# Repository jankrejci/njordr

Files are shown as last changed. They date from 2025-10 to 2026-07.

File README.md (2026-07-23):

# vetroplach

An ultrasonic anemometer: KiCad PCB designs and ESP32-S3 firmware.

## Layout

- `firmware/vetroplach/` — ESP32-S3 firmware (Rust, esp-hal + Embassy)
- `pcb/vetroplach-board/` — main controller board
- `pcb/sensor-board/` — environmental sensor board
- `pcb/components/` — shared KiCad symbol and footprint library
- `nix/` — flake modules: toolchain, checks, dev shells
- `docs/` — design notes and simulations

## Prerequisites

Everything builds through [Nix](https://nixos.org/download/) flakes; no
manual rustup, espup, or KiCad setup is needed. Flashing uses
`probe-rs`; complete the
[probe setup](https://probe.rs/docs/getting-started/probe-setup/#linux-udev-rules),
especially the udev rules on Linux.

## Firmware

Enter the dev shell (pins the Xtensa toolchain, probe-rs, espflash) and
build from the crate directory:

```bash
nix develop
cd firmware/vetroplach
cargo build --release
```

Build and flash:

```bash
cargo run --release
```

Or run an example:

```bash
cargo run --release --example sonic-dual
```

## PCB

DRC/ERC gates and fabrication outputs run through the flake:

```bash
nix develop .#pcb    # KiCad + kibot shell
nix run .#kibot -- -c jlcpcb.kibot.yaml \
  -b pcb/vetroplach-board/vetroplach-board.kicad_pcb \
  -e pcb/vetroplach-board/vetroplach-board.kicad_sch \
  -d fab/vetroplach-board/
```

## Checks

CI runs the flake checks; the same commands work locally:

```bash
nix build .#ci-format    # cargo fmt + nixfmt
nix build .#ci-clippy    # firmware clippy
nix build .#ci-check     # firmware release build, PCB DRC/ERC
nix flake check          # everything
```

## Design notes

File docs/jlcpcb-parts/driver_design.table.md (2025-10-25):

# JLCPCB Component Pricing Tables

MOSFET driver
=============
Component              | Number    | Pcs | Base | Eco | 1 pcs   | 50 pcs  | 500 pcs
-----------------------------------------------------------------------------------
2N7002                 | C8545     | 12  | B    | E   | 0.0137  | 0.0103  | 0.0077 
AO3401A                | C15127    | 3   | B    | E   | 0.0578  | 0.0459  | 0.0399 
FNR5040S822MT          | C167994   | 3   | -    | E   | 0.0878  | 0.0618  | 0.0501 
MT3608L                | C2932326  | 1   | -    | E   | 0.0435  | 0.0435  | 0.0378 
1N5819WS               | C191023   | 1   | B    | E   | 0.0095  | 0.0095  | 0.0077 
FNR5040S220MT          | C167971   | 1   | -    | E   | 0.0539  | 0.0539  | 0.0365 
-----------------------------------------------------------------------------------
TOTAL                  |           |     |      |     | 0.7081  | 0.5536  | 0.4444 
SETUP FEE PER BOARD    |           |     |      |     | 9.0000  | 0.1800  | 0.0180 
-----------------------------------------------------------------------------------
PRICE PER BOARD        |           |     |      |     | 9.7081  | 0.7336  | 0.4624 

RS232 driver
============
Component              | Number    | Pcs | Base | Eco | 1 pcs   | 50 pcs  | 500 pcs
-----------------------------------------------------------------------------------
SP3243EEA-L/TR         | C6853     | 1   | -    | E   | 0.4950  | 0.4095  | 0.3645 
1N4148WS               | C2128     | 6   | B    | E   | 0.0088  | 0.0088  | 0.0058 
-----------------------------------------------------------------------------------
TOTAL                  |           |     |      |     | 0.5478  | 0.4623  | 0.3993 
SETUP FEE PER BOARD    |           |     |      |     | 3.0000  | 0.0600  | 0.0060 
-----------------------------------------------------------------------------------
PRICE PER BOARD        |           |     |      |     | 3.5478  | 0.5223  | 0.4053 

Gate driver
===========
Component              | Number    | Pcs | Base | Eco | 1 pcs   | 50 pcs  | 500 pcs
-----------------------------------------------------------------------------------
2N7002                 | C8545     | 6   | B    | E   | 0.0137  | 0.0137  | 0.0088 
FNR5040S822MT          | C167994   | 3   | -    | E   | 0.0878  | 0.0618  | 0.0501 
MT3608L                | C2932326  | 1   | -    | E   | 0.0435  | 0.0435  | 0.0378 
1N5819WS               | C191023   | 1   | B    | E   | 0.0095  | 0.0095  | 0.0077 
FNR5040S220MT          | C167971   | 1   | -    | E   | 0.0539  | 0.0539  | 0.0365 
IR2104STRPBF-JSM       | C5804631  | 3   | -    | E   | 0.3780  | 0.2100  | 0.1770 
-----------------------------------------------------------------------------------
TOTAL                  |           |     |      |     | 1.5865  | 1.0045  | 0.8161 
SETUP FEE PER BOARD    |           |     |      |     | 12.0000 | 0.2400  | 0.0240 
-----------------------------------------------------------------------------------
PRICE PER BOARD        |           |     |      |     | 13.5865 | 1.2445  | 0.8401 

DRV8300 gate driver
===================
Component              | Number    | Pcs | Base | Eco | 1 pcs   | 50 pcs  | 500 pcs
-----------------------------------------------------------------------------------
2N7002                 | C8545     | 6   | B    | E   | 0.0137  | 0.0137  | 0.0088 
FNR5040S822MT          | C167994   | 3   | -    | E   | 0.0878  | 0.0618  | 0.0501 
MT3608L                | C2932326  | 1   | -    | E   | 0.0435  | 0.0435  | 0.0378 
FNR5040S220MT          | C167971   | 1   | -    | E   | 0.0539  | 0.0539  | 0.0365 
DRV8300DPWR            | C3036056  | 1   | -    | E   | 0.5250  | 0.3675  | 0.2835 
-----------------------------------------------------------------------------------
TOTAL                  |           |     |      |     | 0.9680  | 0.7325  | 0.5609 
SETUP FEE PER BOARD    |           |     |      |     | 12.0000 | 0.2400  | 0.0240 
-----------------------------------------------------------------------------------
PRICE PER BOARD        |           |     |      |     | 12.9680 | 0.9725  | 0.5849

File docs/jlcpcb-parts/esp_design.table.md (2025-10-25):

# JLCPCB Component Pricing Tables

ESP32 RAW design, 8MB flash + 8MB ram
=====================================
Component              | Number    | Pcs | Base | Eco | 1 pcs   | 50 pcs  | 500 pcs
-----------------------------------------------------------------------------------
ESP32-S3R8             | C2913194  | 1   | -    | E   | 3.6210  | 2.9760  | 2.5800 
GD25Q64ESIG            | C2685734  | 1   | -    | E   | 0.6210  | 0.4740  | 0.2730 
XOS25040000LT00351005  | C37635410 | 1   | -    | E   | 0.3645  | 0.2895  | 0.2160 
BWU.FL-IPEX1           | C5137195  | 1   | -    | E   | 0.0329  | 0.0329  | 0.0233 
-----------------------------------------------------------------------------------
TOTAL                  |           |     |      |     | 4.6394  | 3.7724  | 3.0923 
SETUP FEE PER BOARD    |           |     |      |     | 12.0000 | 0.2400  | 0.0240 
-----------------------------------------------------------------------------------
PRICE PER BOARD        |           |     |      |     | 16.6394 | 4.0124  | 3.1163 

ESP32 RAW design, 16MB flash + 8MB ram
======================================
Component              | Number    | Pcs | Base | Eco | 1 pcs   | 50 pcs  | 500 pcs
-----------------------------------------------------------------------------------
ESP32-S3R8             | C2913194  | 1   | -    | E   | 3.6210  | 2.9760  | 2.5800 
W25Q128JVSIQ           | C97521    | 1   | B    | E   | 1.1820  | 0.9285  | 0.7995 
OT2EL4C4JI-111OLP-40M  | C5203551  | 1   | -    | E   | 0.4095  | 0.2670  | 0.2055 
BWU.FL-IPEX1           | C5137195  | 1   | -    | E   | 0.0329  | 0.0329  | 0.0233 
-----------------------------------------------------------------------------------
TOTAL                  |           |     |      |     | 5.2454  | 4.2044  | 3.6083 
SETUP FEE PER BOARD    |           |     |      |     | 9.0000  | 0.1800  | 0.0180 
-----------------------------------------------------------------------------------
PRICE PER BOARD        |           |     |      |     | 14.2454 | 4.3844  | 3.6263 

ESP32 module with integrated antenna, 8MB flash + 2MB ram
=========================================================
Component              | Number    | Pcs | Base | Eco | 1 pcs   | 50 pcs  | 500 pcs
-----------------------------------------------------------------------------------
ESP32-S3-WROOM-1-N8R2  | C2913204  | 1   | -    | -   | 3.9690  | 3.8220  | 3.8220 
-----------------------------------------------------------------------------------
TOTAL                  |           |     |      |     | 3.9690  | 3.8220  | 3.8220 
SETUP FEE PER BOARD    |           |     |      |     | 3.0000  | 0.0600  | 0.0060 
-----------------------------------------------------------------------------------
PRICE PER BOARD        |           |     |      |     | 6.9690  | 3.8820  | 3.8280 

ESP32 module with integrated antenna, 8MB flash + 8 MB ram
==========================================================
Component              | Number    | Pcs | Base | Eco | 1 pcs   | 50 pcs  | 500 pcs
-----------------------------------------------------------------------------------
ESP32-S3-WROOM-1-N8R8  | C2913201  | 1   | -    | -   | 5.2935  | 4.3515  | 3.9240 
-----------------------------------------------------------------------------------
TOTAL                  |           |     |      |     | 5.2935  | 4.3515  | 3.9240 
SETUP FEE PER BOARD    |           |     |      |     | 3.0000  | 0.0600  | 0.0060 
-----------------------------------------------------------------------------------
PRICE PER BOARD        |           |     |      |     | 8.2935  | 4.4115  | 3.9300 

ESP32 module with external antenna, 8MB flash + 2MB ram
=======================================================
Component              | Number    | Pcs | Base | Eco | 1 pcs   | 50 pcs  | 500 pcs
-----------------------------------------------------------------------------------
ESP32-S3-WROOM-1U-N8R2 | C3013944  | 1   | -    | -   | 4.3530  | 4.1250  | 4.1250 
-----------------------------------------------------------------------------------
TOTAL                  |           |     |      |     | 4.3530  | 4.1250  | 4.1250 
SETUP FEE PER BOARD    |           |     |      |     | 3.0000  | 0.0600  | 0.0060 
-----------------------------------------------------------------------------------
PRICE PER BOARD        |           |     |      |     | 7.3530  | 4.1850  | 4.1310 

ESP32 module with external antenna, 8MB flash + 8MB ram
=======================================================
Component              | Number    | Pcs | Base | Eco | 1 pcs   | 50 pcs  | 500 pcs
-----------------------------------------------------------------------------------
ESP32-S3-WROOM-1U-N8R8 | C2980300  | 1   | -    | -   | 5.3940  | 4.4520  | 4.0980 
-----------------------------------------------------------------------------------
TOTAL                  |           |     |      |     | 5.3940  | 4.4520  | 4.0980 
SETUP FEE PER BOARD    |           |     |      |     | 3.0000  | 0.0600  | 0.0060 
-----------------------------------------------------------------------------------
PRICE PER BOARD        |           |     |      |     | 8.3940  | 4.5120  | 4.1040

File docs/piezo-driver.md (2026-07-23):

# Piezo Driver

The Vetroplach driver uses a half-bridge configuration with LC resonance to boost 20V up to ~100Vpp at the transducer. Same transducer works for both transmit and receive.

## Circuit Design

### Half-Bridge with Resonant Tank

Two N-channel MOSFETs switch a node between +20V and ground. The switching drives an inductor that forms a resonant tank with the transducer's capacitance. At resonance (40kHz), the LC circuit naturally amplifies voltage - no transformer or high-voltage supply needed.

Bootstrap capacitor lets the high-side MOSFET work with a single supply. It charges when the low-side switch is on, then provides gate drive voltage when needed.

## Signal Path

**Transmit**: Gate driver alternates the MOSFETs at 40kHz. First few cycles ramp up amplitude, then full power transmission. Current sense resistor in the return path monitors what's happening.

**Receive**: After transmit burst stops, same transducer picks up echoes. AC coupling cap blocks DC and passes the signal to external processing. The coupling cap needs to handle the full drive voltage swing.

## Why This Design

**Compared to single transistor**: Would need >100V supply and still wouldn't drive efficiently. Not practical.

**Compared to MAX232**: [QingStation](https://github.com/majianjia/QingStation/blob/main/doc/anemometer.md#driver-design) tried this clever hack using RS-232 chips to get ±10V from 3V. Problem is the charge pump creates noise that messes with the sensitive receive circuit. Works but not ideal for precision timing.

**Compared to transformer**: [DL1GLH design](https://www.dl1glh.de/ultrasonic-anemometer.html) uses transformers for voltage boost and impedance matching. Works great but transformers are bulky and expensive. The resonant inductor does similar voltage boost without the hassle.

## Notes

The 40kHz frequency is a sweet spot - transducers are cheap and common, air attenuation isn't too bad, wavelength gives decent resolution, and microcontrollers can handle the timing easily.

Resonant Q factor matters: higher Q means more voltage gain but longer ring-down. The inductor value balances fast response with good amplitude.

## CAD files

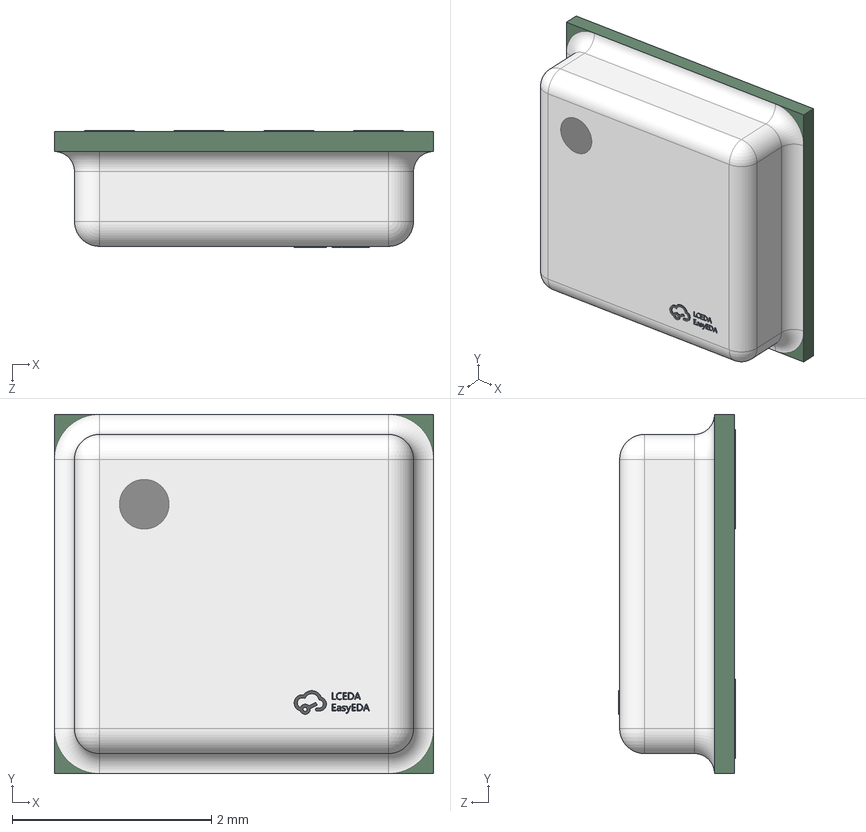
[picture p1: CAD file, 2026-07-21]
pcb/components/packages/QFN-8-L3.8-W3.6-H1.2-P0.9.step
3.80 x 3.60 x 1.17 mm

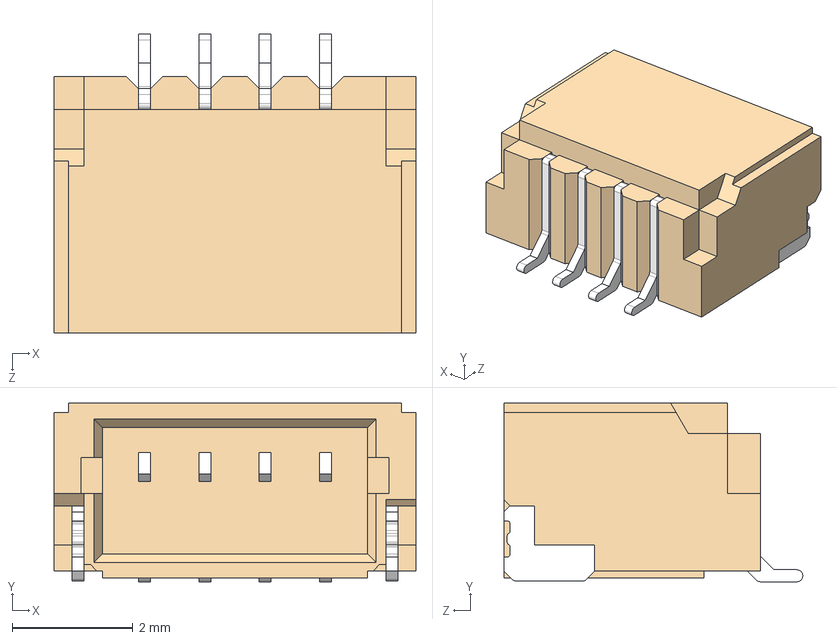
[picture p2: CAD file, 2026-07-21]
pcb/components/packages/SM04B-SRSS-TB.stp
6.00 x 2.96 x 4.95 mm

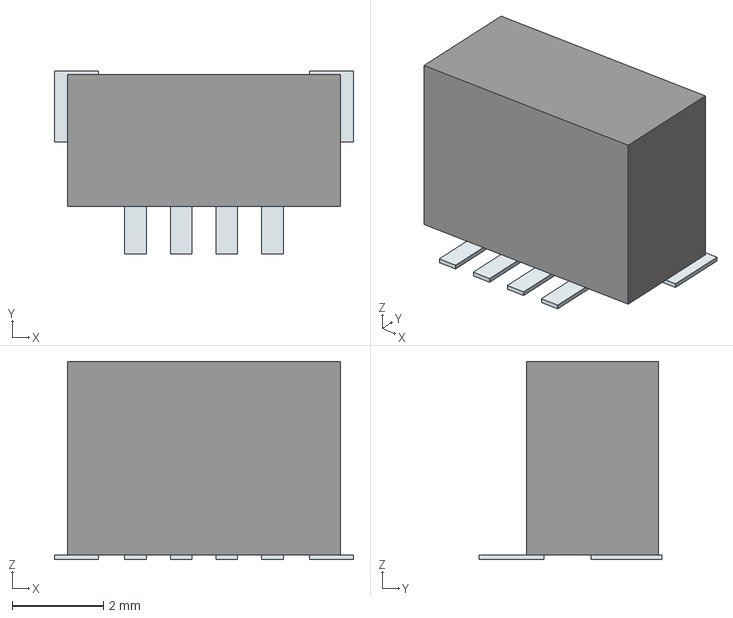
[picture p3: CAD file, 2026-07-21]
pcb/components/packages/BM04B-SRSS-TBT.stp
6.56 x 4.02 x 4.35 mm
Pins

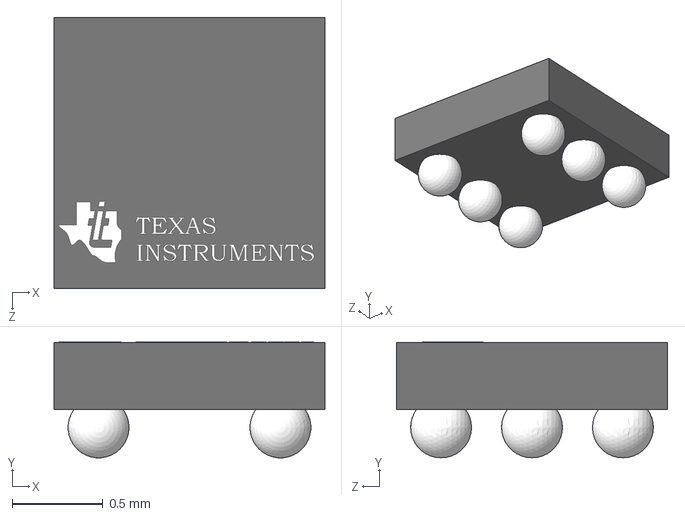
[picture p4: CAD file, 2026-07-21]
pcb/components/packages/HDC2010YPAR.stp
1.49 x 0.635 x 1.49 mm

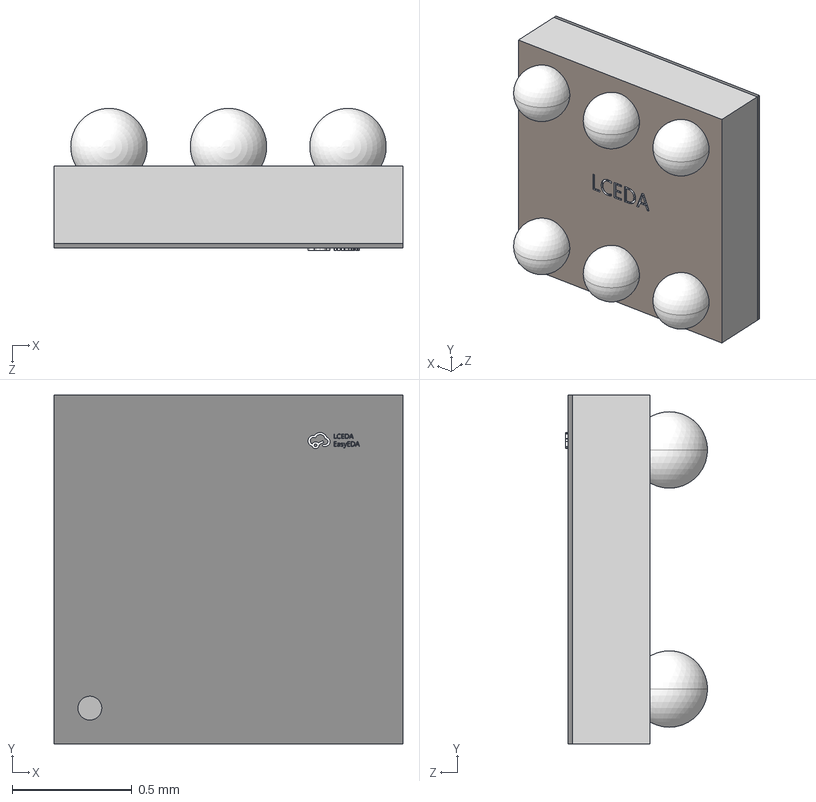
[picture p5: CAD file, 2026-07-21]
pcb/components/packages/DSBGA-6-L1.5-W1.5-H0.6-P0.50.step
1.46 x 1.46 x 0.595 mm

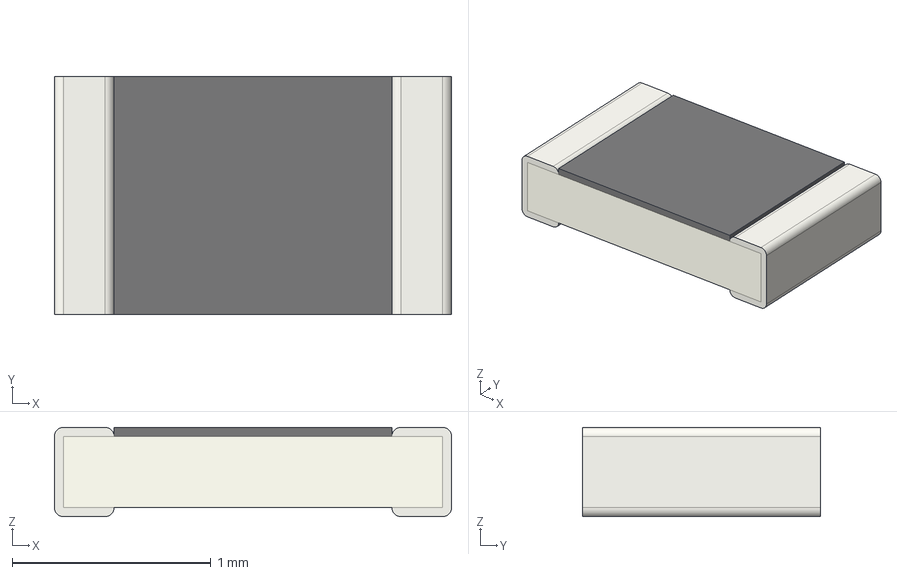
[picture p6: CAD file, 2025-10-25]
pcb/components/packages/R-0805.step
2.00 x 1.20 x 0.45 mm

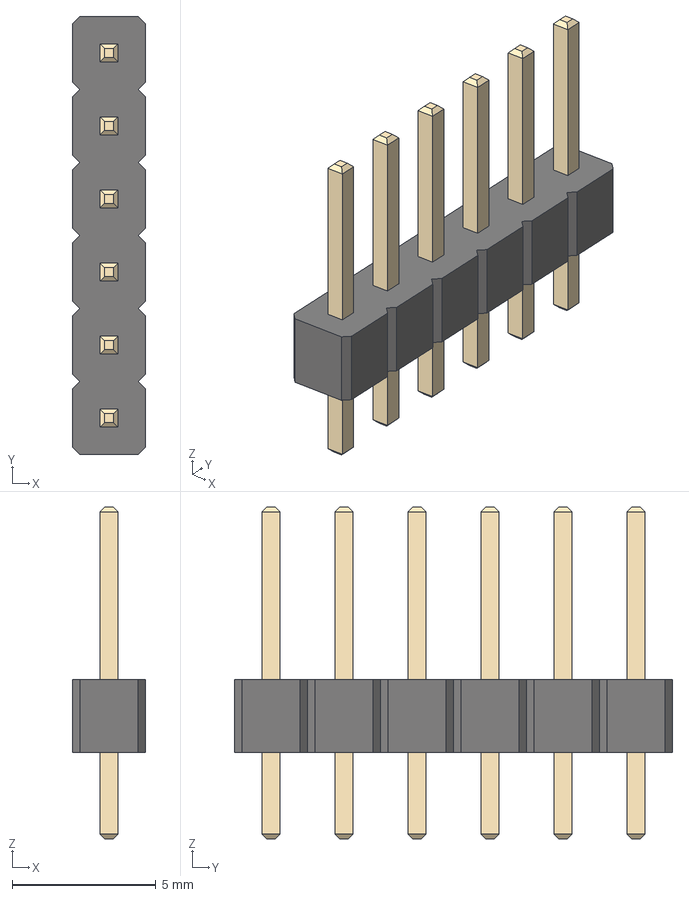
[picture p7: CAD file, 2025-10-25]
pcb/components/packages/PinHeader-1x06-P2.54-Vertical.step
2.54 x 15.2 x 11.5 mm

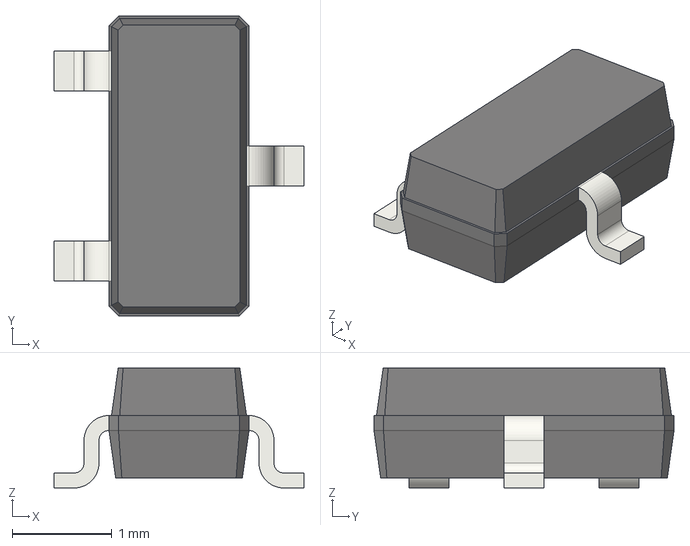
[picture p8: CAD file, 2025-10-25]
pcb/components/packages/SOT-23.step
2.50 x 3.00 x 1.20 mm

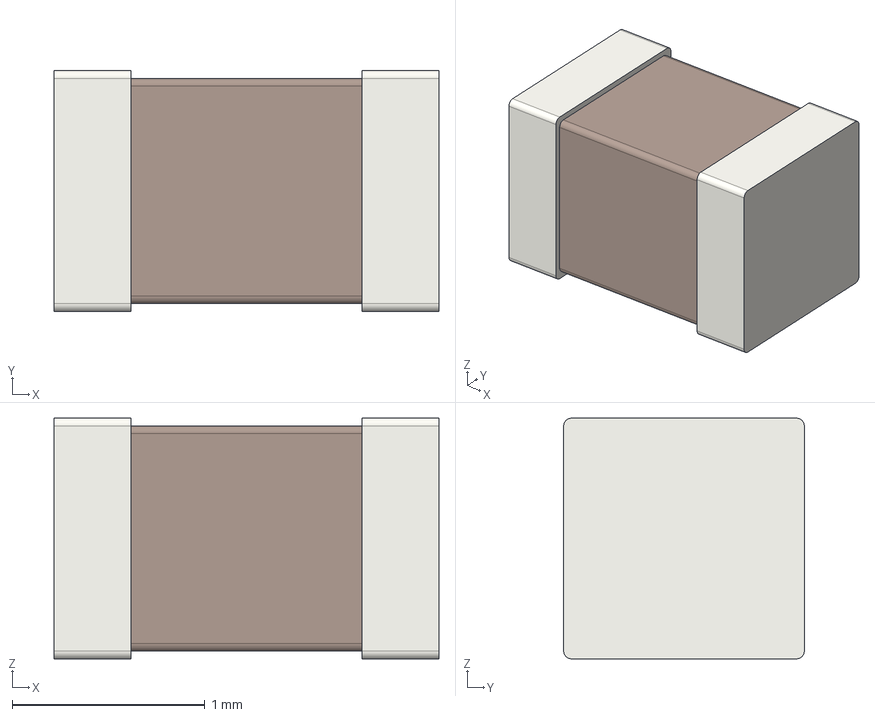
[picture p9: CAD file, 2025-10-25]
pcb/components/packages/C-0805.step
2.00 x 1.25 x 1.25 mm

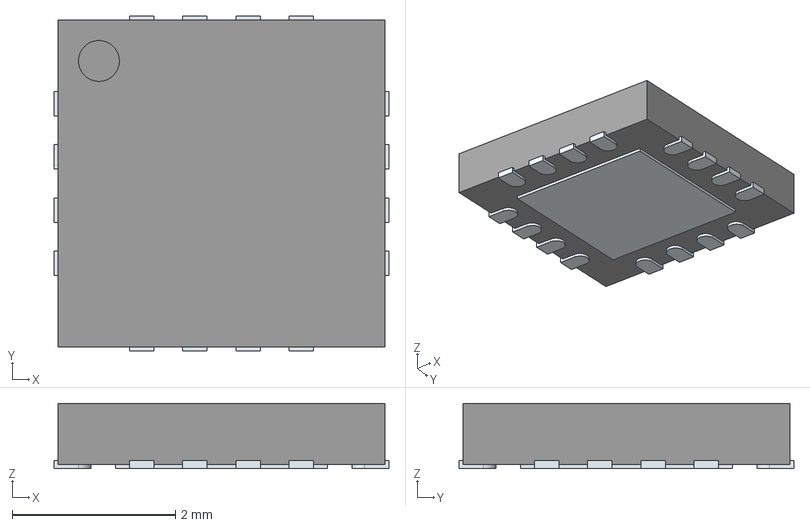
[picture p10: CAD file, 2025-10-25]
pcb/components/packages/WQFN-16-4.0x4.0.stp
4.10 x 4.10 x 0.8 mm
ThermalPin
PinsArrayLR
PinsArrayTB

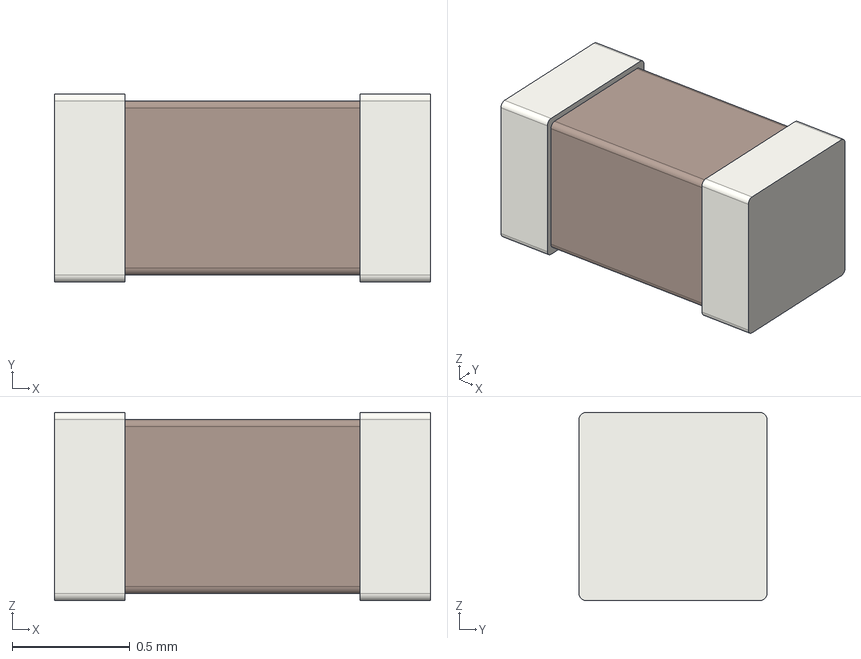
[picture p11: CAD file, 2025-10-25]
pcb/components/packages/C-0603.step
1.60 x 0.8 x 0.8 mm

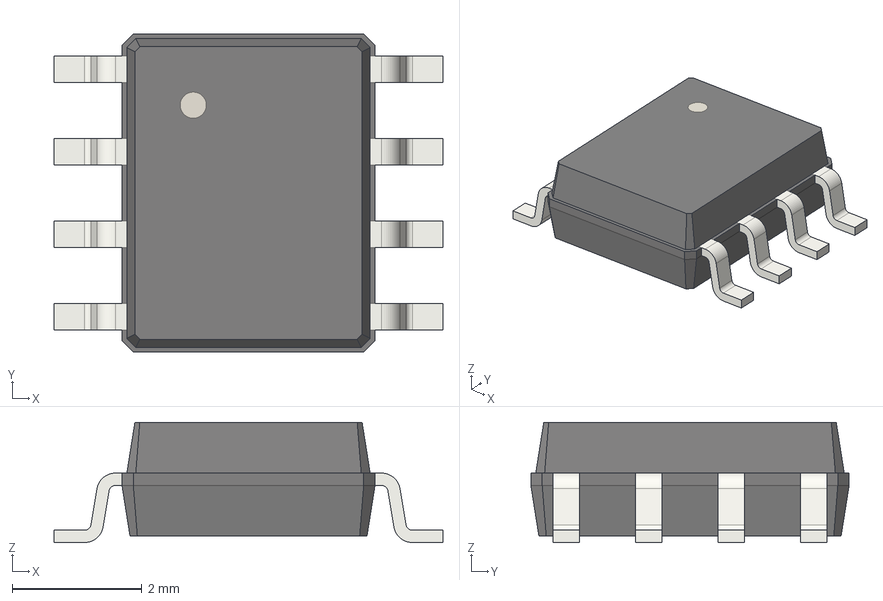
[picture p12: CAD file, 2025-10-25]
pcb/components/packages/SO-8-3.9x4.9-P1.27.step
6.00 x 4.91 x 1.85 mm

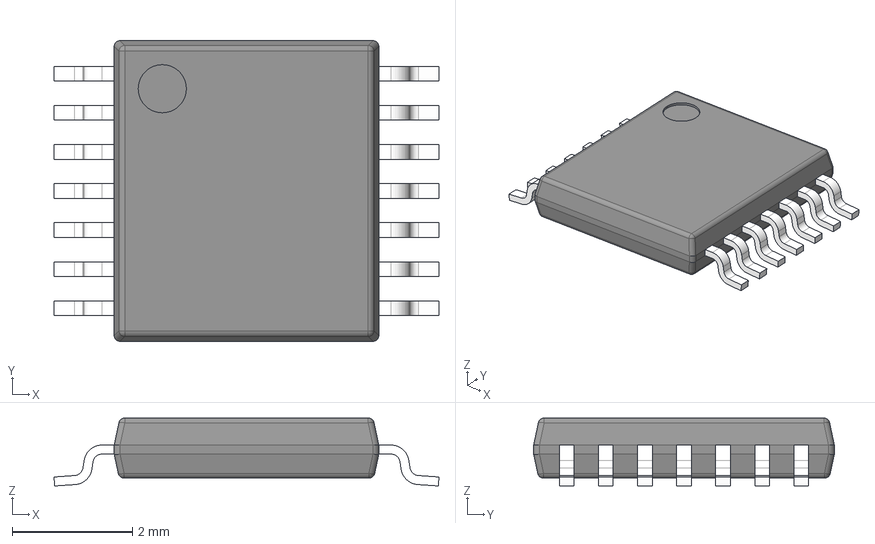
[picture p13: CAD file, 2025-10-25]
pcb/components/packages/TSSOP-14-4.4x5.0.stp
6.40 x 5.00 x 1.13 mm
BODY-TSSOP
LEAD-TSSOP x 14
PIN1

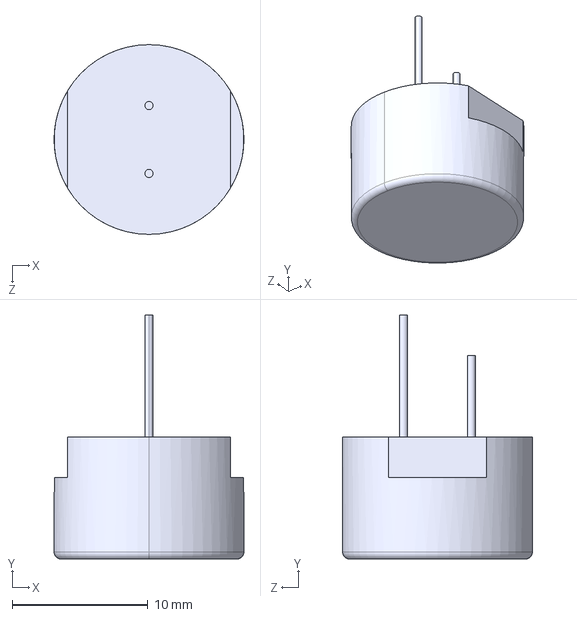
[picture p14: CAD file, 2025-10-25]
pcb/components/packages/CUSA-TR65-065-2200-TH68.step
14.0 x 18.0 x 14.0 mm

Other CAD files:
pcb/components/packages/D-SOD-323.step
pcb/components/packages/R-0603.step
pcb/components/packages/SOT-23-6.step
pcb/components/packages/L-Axial-L7.0-D3.3-P10.16.step
pcb/components/packages/C-1206.step
pcb/components/packages/L-Axial-L12.0-D5.0-P15.24.step
pcb/components/packages/TSSOP-20-4.4x6.5.step

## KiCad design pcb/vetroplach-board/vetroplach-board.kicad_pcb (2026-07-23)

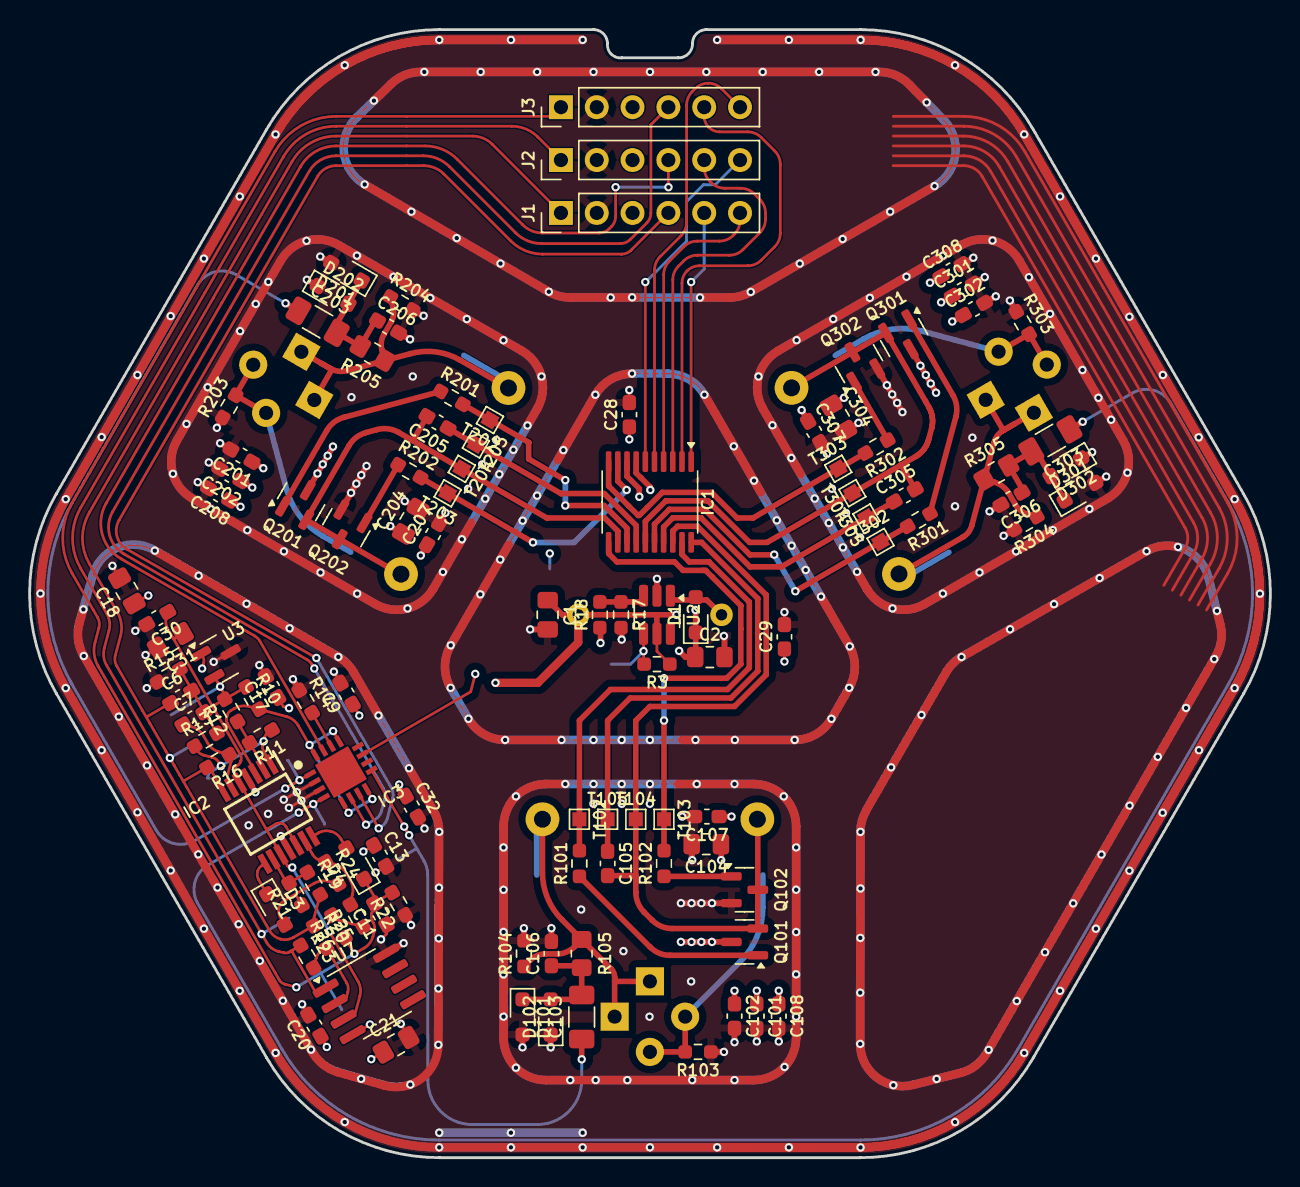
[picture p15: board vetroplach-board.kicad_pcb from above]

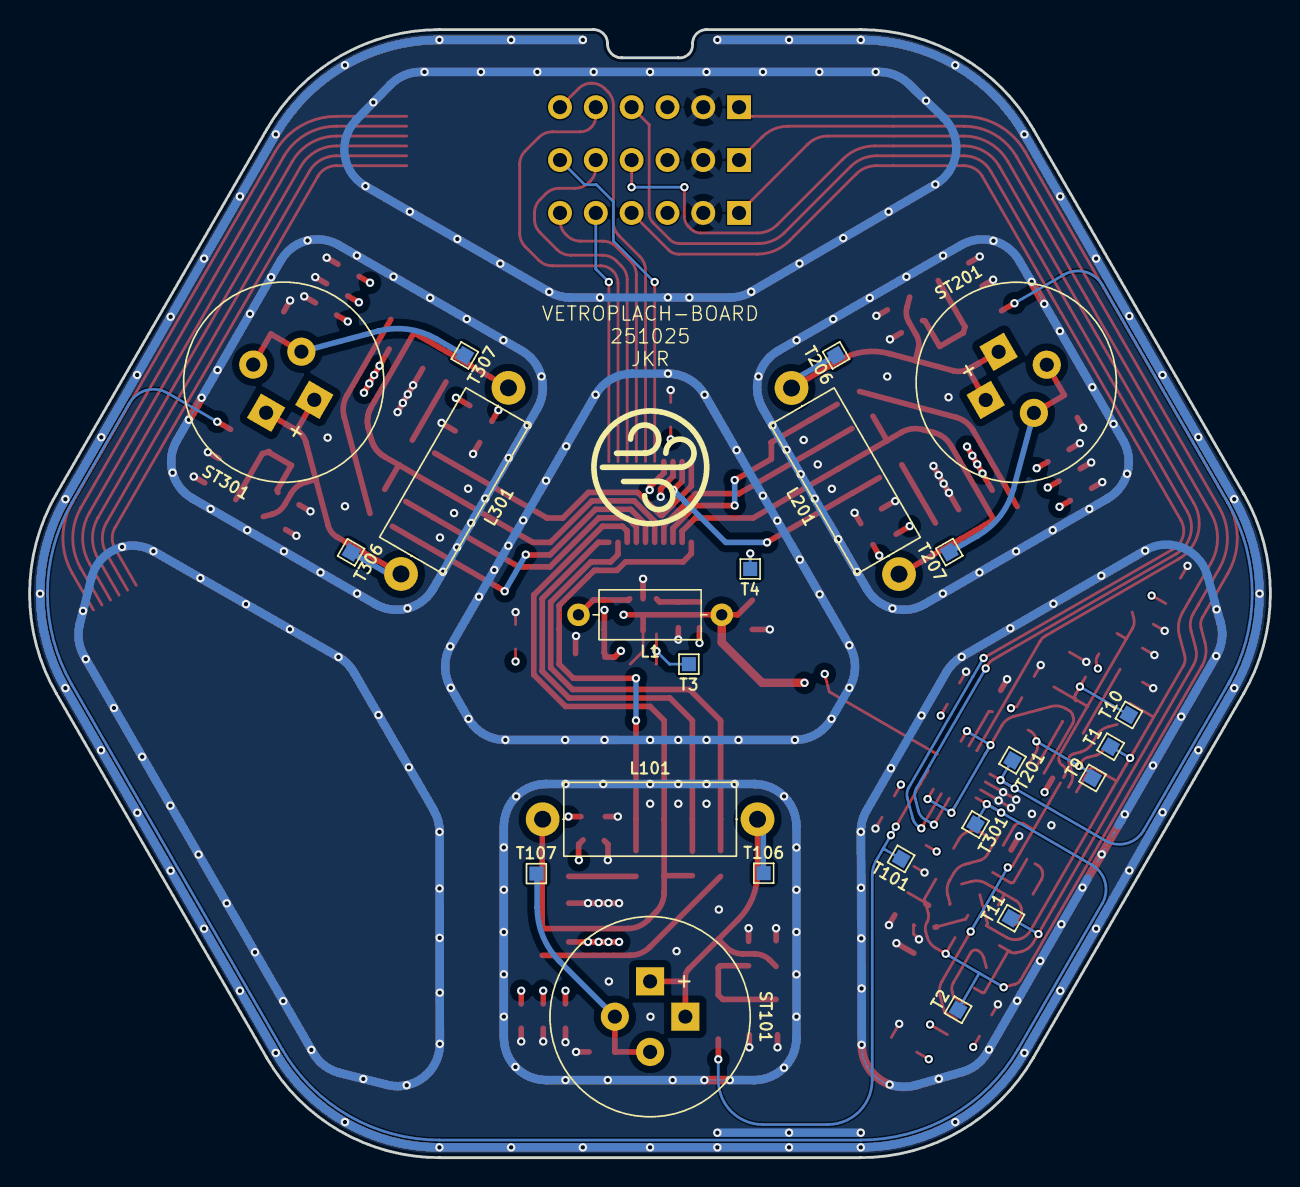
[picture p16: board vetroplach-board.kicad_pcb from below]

Board: 4 copper layers, 88.0 x 80.0 mm, 132 parts (23 on the bottom side), 62 nets.

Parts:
C1, C2, C18, C21, C31, C104, C204, C304: 22u; C-0805-HandSolder
C6, C106, C206, C306: 330p; C-0603-HandSolder
C7: 220p; C-0603-HandSolder
C9, C11, C13, C17, C20, C28, C29, C30, C32, C101, C105, C107, C108, C201, C205, C207, C208, C301, C305, C307, C308: 100n; C-0603-HandSolder
C102, C202, C302: 1u; C-0603-HandSolder
C103, C203, C303: 1n; C-1206-HandSolder
D1: 1N5819WS; D-SOD-323-HandSolder
D3, D4, D101, D102, D201, D202, D301, D302: 1N4148WS; D-SOD-323-HandSolder
IC1: DRV8300DPWR; TSSOP-20-4.4x6.5
IC2: GS8054; TSSOP-14-4.4x5.0
IC3: TMUX741x; WQFN-16-4.0x4.0
J1, J2, J3: Conn_01x06; PinHeader-1x06-P2.54mm-Vertical
L1: 6u8; L-Axial-L7.0-D3.3mm-P10.16
L101, L201, L301: 8.2mH; L-Axial-L12.0-D5.0-P15.24
Q101, Q102, Q201, Q202, Q301, Q302: 2N7002; SOT-23
R3, R12, R14, R17, R20: 10k; R-0603-HandSolder
R10, R11, R23: 100k; R-0603-HandSolder
R13, R104, R204, R304: 2k2; R-0603-HandSolder
R15: 4k7; R-0603-HandSolder
R16: 150k; R-0603-HandSolder
R18: 330k; R-0603-HandSolder
R19: 2k; R-0603-HandSolder
R21, R22: 1k; R-0603-HandSolder
R24, R25, R26: 3k; R-0603-HandSolder
R101, R102, R103, R201, R202, R203, R301, R302, R303: 10R; R-0603-HandSolder
R105, R205, R305: 0R; R-0805-HandSolder
ST101, ST201, ST301: Speaker_Ultrasound; CUSA-TR65-065-2200-TH68
T1, T2, T3, T4, T9, T10, T11, T101, T102, T103, T104, T105, T106, T107, T201, T202, T203, T204, T205, T206, T207, T301, T302, T303, T304, T305, T306, T307: TestPoint; TestPoint-Pad-1.0x1.0
U2: MT3608; SOT-23-6-HandSolder
U3: REF3012; SOT-23
U7: LM393; SOIC-8-3.9x4.9-P1.27

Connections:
+3.3V: C1.1, C9.1, C13.1, C17.1, C18.1, C20.1, C21.1, C32.1, IC2.4 (V+), J1.3, J2.3, J3.3, L1.1, R3.1, U2.5 (IN), U3.1 (IN), U7.4 (V-)
+24V: C2.1, C28.1, C29.1, C101.1, C102.1, C104.1, C107.1, C108.1, C201.1, C202.1, C204.1, C207.1, C208.1, C301.1, C302.1, C304.1, C307.1, C308.1, D1.1 (K), IC1.7 (GVDD), IC3.11 (VDD), Q101.3 (D), Q201.3 (D), Q301.3 (D), R18.1, T4.1
/ECHO: C6.1, IC2.7, J1.1, R16.2, R19.2, R20.1, T1.1
/EDGE: J2.1, R23.1, T11.1, U7.1
/ENVELOPE: C11.2, D4.1 (K), J3.1, R22.2, R26.1, T2.1
/RX_EN_CH1: IC3.7 (SEL3), J1.4
/RX_EN_CH2: IC3.15 (SEL1), J2.4
/RX_EN_CH3: IC3.6 (SEL4), J3.4
/interface/BOOTSTRAP_CH1: C105.1, IC1.20 (BSTA), T105.1
/interface/BOOTSTRAP_CH2: C205.1, IC1.14 (BSTC), T205.1
/interface/BOOTSTRAP_CH3: C305.1, IC1.17 (BSTB), T305.1
/interface/GATE_HIGH_CH1: IC1.19 (GHA), R101.2, T102.1
/interface/GATE_HIGH_CH2: IC1.13 (GHC), R201.2, T202.1
/interface/GATE_HIGH_CH3: IC1.16 (GHB), R301.2, T302.1
/interface/GATE_LOW_CH1: IC1.11 (GLA), R102.2, T103.1
/interface/GATE_LOW_CH2: IC1.9 (GLC), R202.2, T203.1
/interface/GATE_LOW_CH3: IC1.10 (GLB), R302.2, T303.1
/interface/INPUT_HIGH_CH1: IC1.1 (INHA), J1.5
/interface/INPUT_HIGH_CH2: IC1.3 (INHC), J2.5
/interface/INPUT_HIGH_CH3: IC1.2 (INHB), J3.5
/interface/INPUT_LOW_CH1: IC1.4 (INLA), J1.6
/interface/INPUT_LOW_CH2: IC1.6 (INLC), J2.6
/interface/INPUT_LOW_CH3: IC1.5 (INLB), J3.6
/interface/SENSE_CH1: C105.2, IC1.18 (SHA), L101.1, Q101.2 (S), Q102.3 (D), T104.1
/interface/SENSE_CH2: C205.2, IC1.12 (SHC), L201.1, Q201.2 (S), Q202.3 (D), T204.1
/interface/SENSE_CH3: C305.2, IC1.15 (SHB), L301.1, Q301.2 (S), Q302.3 (D), T304.1
/interface/~BOOSTER_EN: R3.2, T3.1, U2.4 (EN)
/signal-priming/ECHO_CH1: C103.1, IC3.9 (S3), T101.1
/signal-priming/ECHO_CH2: C203.1, IC3.1 (S1), T201.1
/signal-priming/ECHO_CH3: C303.1, IC3.4 (S4), T301.1
/signal-priming/ECHO_IN: IC2.3 (+), IC3.5 (D4), IC3.8 (D3), IC3.13 (D2), IC3.16 (D1), R10.2
/signal-priming/STAGE_A: IC2.1, R11.1, R13.1, T9.1
/signal-priming/VREF: C30.1, C31.1, IC2.5 (+), IC2.10 (+), IC2.12 (+), R10.1, R12.2, T10.1, U3.2 (OUT), U7.3 (+)
/sonic-ch1/SONIC: L101.2, R104.1, R105.1, ST101.1, T106.1
/sonic-ch2/SONIC: L201.2, R204.1, R205.1, ST201.1, T206.1
/sonic-ch3/SONIC: L301.2, R304.1, R305.1, ST301.1, T306.1
GND: C1.2, C2.2, C9.2, C11.1, C13.2, C17.2, C18.2, C20.2, C21.2, C28.2, C29.2, C30.2, C31.2, C32.2, C101.2, C102.2, C104.2, C106.2, C107.2, C108.2, C201.2, C202.2, C204.2, C206.2, C207.2, C208.2, C301.2, C302.2, C304.2, C306.2, C307.2, C308.2, D101.2 (A), D102.1 (K), D201.2 (A), D202.1 (K), D301.2 (A), D302.1 (K), IC1.8 (GND), IC2.11 (V-), IC3.2 (VSS), IC3.3 (GND), J1.2, J2.2, J3.2, Q102.2 (S), Q202.2 (S), Q302.2 (S), R14.1, R15.1, R17.2, R22.1, R103.1, R104.2, R203.1, R204.2, R303.1, R304.2, U2.2 (GND), U3.3 (GND), U7.8 (V+)
unnamed: C6.2, C7.2, R13.2, R15.2
unnamed: D1.2 (A), L1.2, U2.1 (SW)
unnamed: D3.2 (A), R21.1, R24.2
unnamed: D3.1 (K), IC2.8
unnamed: D4.2 (A), IC2.14
unnamed: C103.2, C106.1, D101.1 (K), D102.2 (A), R105.2
unnamed: C203.2, C206.1, D201.1 (K), D202.2 (A), R205.2
unnamed: C303.2, C306.1, D301.1 (K), D302.2 (A), R305.2
unnamed: IC2.2 (-), R11.2, R12.1
unnamed: C7.1, IC2.6 (-), R16.1
unnamed: IC2.9 (-), R19.1, R21.2
unnamed: IC2.13 (-), R24.1, R25.2
unnamed: IC3.14 (SEL2), R14.2
unnamed: Q101.1 (G), R101.1
unnamed: Q102.1 (G), R102.1
unnamed: Q201.1 (G), R201.1
unnamed: Q202.1 (G), R202.1
unnamed: Q301.1 (G), R301.1
unnamed: Q302.1 (G), R302.1
unnamed: R25.1, R26.2
unnamed: R103.2, ST101.2, T107.1
unnamed: R203.2, ST201.2, T207.1
unnamed: R303.2, ST301.2, T307.1
unnamed: R17.1, R18.2, U2.3 (FB)
unnamed: R20.2, R23.2, U7.2 (-)

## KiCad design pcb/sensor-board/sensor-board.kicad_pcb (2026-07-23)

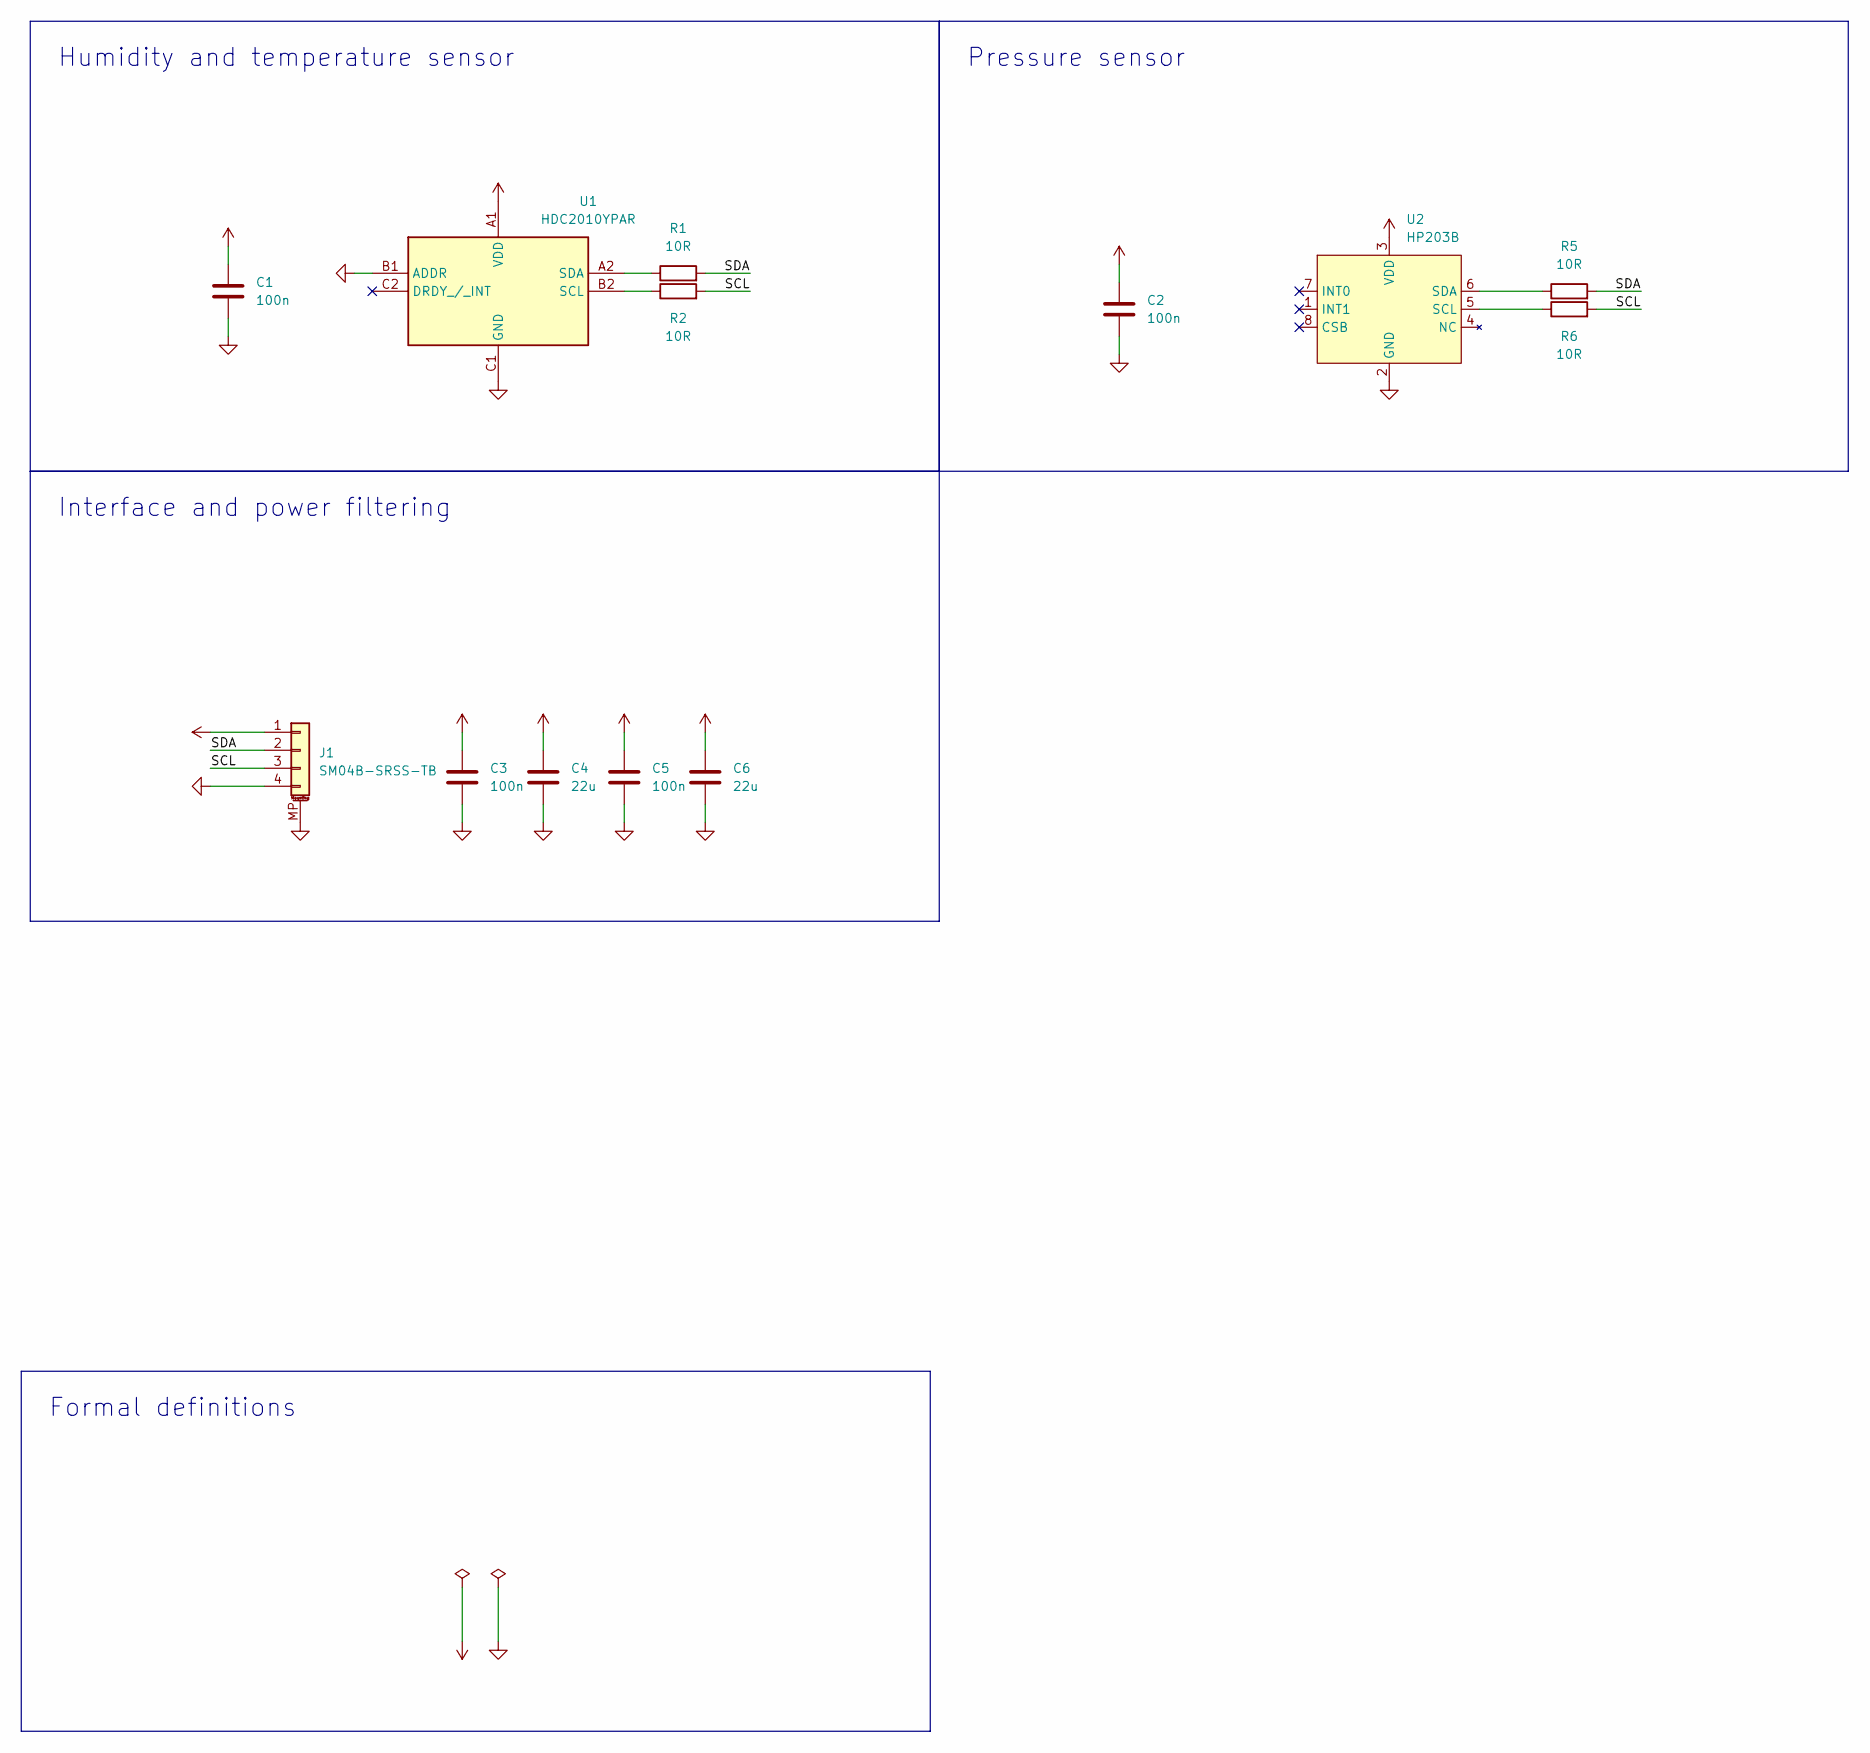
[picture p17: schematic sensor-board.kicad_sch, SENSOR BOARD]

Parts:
C1, C2, C3, C5: 100n; C-0603-HandSolder; LCSC C14663
C4, C6: 22u; C-0805-HandSolder; LCSC C59461
J1: SM04B-SRSS-TB; LCSC C160404
R1, R2, R5, R6: 10R; R-0603-HandSolder; LCSC C22859
U1: HDC2010YPAR; DSBGA-6-1.5x1.5; LCSC C477922
U2: HP203B; QFN-8-HP203B; LCSC C138665

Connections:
/SCL: J1.3, R2.2, R6.2
/SDA: J1.2, R1.2, R5.2
GND: C1.2, C2.2, C3.2, C4.2, C5.2, C6.2, J1.4, J1.MP (MountPin), U1.B1 (ADDR), U1.C1 (GND), U2.2 (GND)
unnamed: R2.1, U1.B2 (SCL)
unnamed: R1.1, U1.A2 (SDA)
unnamed: R6.1, U2.5 (SCL)
unnamed: R5.1, U2.6 (SDA)
VCC: C1.1, C2.1, C3.1, C4.1, C5.1, C6.1, J1.1, U1.A1 (VDD), U2.3 (VDD)

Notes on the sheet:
Interface and power filtering
Pressure sensor
Formal definitions
Humidity and temperature sensor

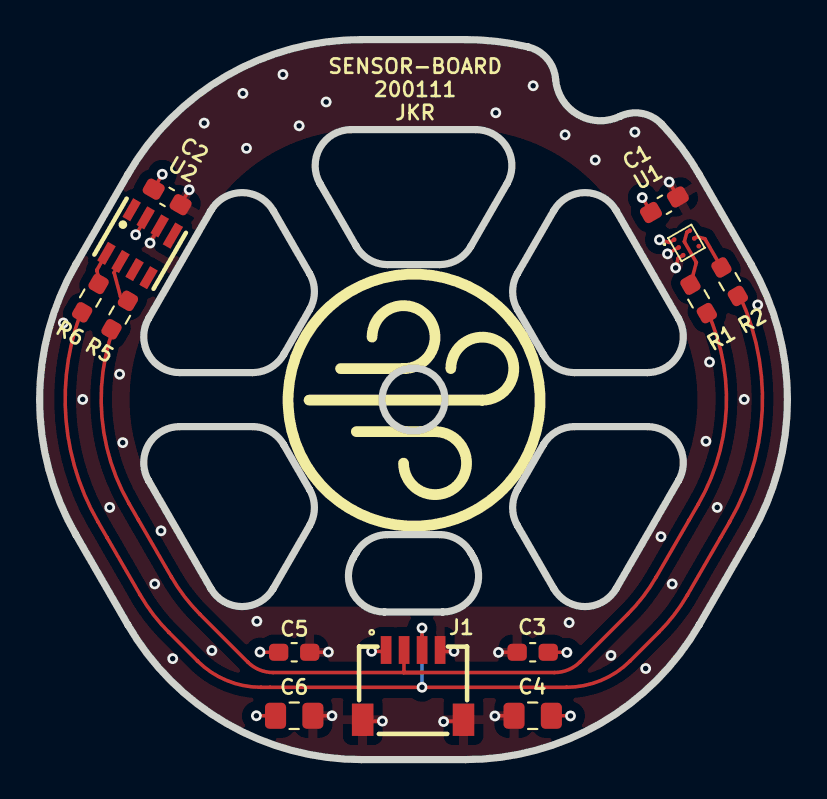
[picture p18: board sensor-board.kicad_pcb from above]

Board: 4 copper layers, 41.5 x 40.0 mm, 13 parts (0 on the bottom side), 8 nets.

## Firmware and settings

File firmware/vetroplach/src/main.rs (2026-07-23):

#![no_std]
#![no_main]

pub mod sonic;

use defmt::debug;
use embassy_executor::Spawner;
use embassy_time::{Duration, Timer};
use esp_hal::timer::systimer::SystemTimer;
use esp_hal::{
    self,
    clock::CpuClock,
    mcpwm::{operator::PwmPinConfig, timer::PwmWorkingMode, McPwm, PeripheralClockConfig},
    time::Rate,
};
use panic_rtt_target as _;

#[esp_hal_embassy::main]
async fn main(_spawner: Spawner) {
    rtt_target::rtt_init_defmt!();

    let config = esp_hal::Config::default().with_cpu_clock(CpuClock::max());
    let peripherals = esp_hal::init(config);

    let timer0 = SystemTimer::new(peripherals.SYSTIMER);
    esp_hal_embassy::init(timer0.alarm0);

    debug!("Embassy initialized!");

    let pin = peripherals.GPIO2;

    let clock_cfg = PeripheralClockConfig::with_frequency(Rate::from_mhz(40))
        .expect("BUG: Failed to configure clock");

    let mut mcpwm = McPwm::new(peripherals.MCPWM0, clock_cfg);

    // connect operator0 to timer0
    mcpwm.operator0.set_timer(&mcpwm.timer0);
    // connect operator0 to pin
    let mut pwm_pin = mcpwm
        .operator0
        .with_pin_a(pin, PwmPinConfig::UP_ACTIVE_HIGH);

    // start timer with timestamp values in the range of 0..=99 and a frequency
    // of 40 kHz
    let timer_clock_cfg = clock_cfg
        .timer_clock_with_frequency(99, PwmWorkingMode::Increase, Rate::from_khz(40))
        .expect("BUG: Failed to configure timer");

    mcpwm.timer0.start(timer_clock_cfg);

    const PWM_BURST_DURATION: Duration = Duration::from_millis(1);
    const PWM_BURST_PERIOD: Duration = Duration::from_millis(100);

    loop {
        // pin will be high 50% of the time
        pwm_pin.set_timestamp(50);
        Timer::after(PWM_BURST_DURATION).await;
        pwm_pin.set_timestamp(0);
        Timer::after(PWM_BURST_PERIOD).await;
    }
}

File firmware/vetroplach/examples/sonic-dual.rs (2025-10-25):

#![no_std]
#![no_main]

use defmt::info;
use embassy_executor::Spawner;
use embassy_time::{Duration, Timer};
use esp_hal::{
    self,
    clock::CpuClock,
    rmt::{Rmt, TxChannelConfig, TxChannelCreator},
    time::{self, Rate},
    timer::systimer::SystemTimer,
};
use panic_rtt_target as _;

#[path = "../src/sonic.rs"]
mod sonic;
use sonic::{Sonic, SonicMode};

defmt::timestamp!(
    "{=u64:us}",
    time::Instant::now().duration_since_epoch().as_micros()
);

#[esp_hal_embassy::main]
async fn main(_spawner: Spawner) {
    rtt_target::rtt_init_defmt!();

    let config = esp_hal::Config::default().with_cpu_clock(CpuClock::max());
    let peripherals = esp_hal::init(config);

    let timer0 = SystemTimer::new(peripherals.SYSTIMER);
    esp_hal_embassy::init(timer0.alarm0);

    info!("Initializing dual ultrasonic system: TX sensor + RX sensor");

    let rmt = Rmt::new(peripherals.RMT, Rate::from_mhz(80))
        .unwrap()
        .into_async();

    let mut sensor_a: Sonic<0> = Sonic::new(
        rmt.channel0
            .configure_tx(
                peripherals.GPIO4,
                TxChannelConfig::default().with_clk_divider(1),
            )
            .unwrap(),
        peripherals.GPIO37,
        peripherals.GPIO41,
    );
    let mut sensor_b: Sonic<1> = Sonic::new(
        rmt.channel1
            .configure_tx(
                peripherals.GPIO5,
                TxChannelConfig::default().with_clk_divider(1),
            )
            .unwrap(),
        peripherals.GPIO36,
        peripherals.GPIO40,
    );
    let mut sensor_c: Sonic<2> = Sonic::new(
        rmt.channel2
            .configure_tx(
                peripherals.GPIO6,
                TxChannelConfig::default().with_clk_divider(1),
            )
            .unwrap(),
        peripherals.GPIO35,
        peripherals.GPIO39,
    );

    sensor_a.set_mode(SonicMode::Receive);
    sensor_b.set_mode(SonicMode::Disabled);
    sensor_c.set_mode(SonicMode::Transmit);
    const FREQUENCY: f32 = 39000.0;
    loop {
        info!(
            "=== TX sensor: Triggering {} kHz burst ===",
            FREQUENCY / 1000.0
        );
        sensor_c.set_frequency(FREQUENCY, 0.5);
        sensor_c.transmit_burst().await.unwrap();
        Timer::after(Duration::from_millis(1000)).await;
    }
}

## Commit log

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2025-07-27 firmware: Add simple example based on esp-generate template
    - use embassy as a runtime
    - use defmt for logging
    - use probe-rs for flashing / debugging
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2025-07-27 firmware: Add basic PWM burst generator
    - modify the hello world example to be usable as a simple generator
    for analog circuitry testing
2025-07-27 firmware: Introduce examples
    - add examples folder and copy the pwm example there, this is more
    convenient for development
2025-07-27 firmware: Update the flake to be working also for NixOS system
    - toolchain installed via espup rely on shared libraries to be
    achievable on expected path, which is not the case in NixOS,
    so there is need to patch binaries to work properly
2025-07-27 firmware: Move all the firmware related files into subfolder
    - there will be multiple components including kicad board files
    so keep it organized
2025-07-27 firmware: Pin xtensa toolchain versions
    - avoid discrepancies between CI and local build system
2025-07-27 transceiver: Add empty kicad project for njordr-transceiver
    - ignore all temporary files
    [njordr-board.kicad_pcb, njordr-board.kicad_sch]
2025-07-27 transceiver: Add transceiver circuitry and board
    - create a board for testing of the analog switches
    [njordr-board.kicad_pcb, njordr-board.kicad_sch, njordr-transceiver.kicad_pcb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]
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2025-10-25 firmware: Introduce the sonic module
    - introduce the claude software engineer agent
    - refactor the flake to be working on nixos as well on other distros
    - use the RMT peripheral to handle pulse generator
    - introduce the sonic module to handle the ultrasonic transducer
    - add frequency change support
2025-10-25 board: Create a board with all components integrated
    - move the transceiver folder to njordr-board, sensors will be assembled
    directly on the main board
    - implement the sonic driver
    - add the interface sheet
    - add simulation experiments
    - use mosfet gate driver for signal generator
    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
    [C_0603_1608Metric.step, C_0805_2012Metric.step, C_1206_3216Metric.step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]
2025-10-25 docs: Improve the board documentation
    - introduce script for component price evaluation
    - add basic driver and input filter simulations
    - describe the piezo driver
    - add DRV8300 sonic driver variant
2025-10-25 board: Improve board markings
    - rotate reference labels
    - add connector description
    - add logo
    [interface.kicad_sch, njordr-board.kicad_pcb, njordr-board.kicad_sch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]
2025-10-25 board: Use lower resistor values for the envelope detector
    - try to lower impedance to have higher stability
    [njordr-board.kicad_pcb, signal-priming.kicad_sch]
2026-07-21 sensor-board: Introduce sensor board
    - create new folder for the subproject
    - create initial kicad project
    - add required components into the share library
    - cleanup the library
    [BM04B-SRSS-TBT.stp, C-0603.step, C-0805.step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]
2026-07-21 njordr-board: Use updated library symbols and packages
    [controller.kicad_sch, interface.kicad_sch, njordr-board.kicad_pcb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]
2026-07-21 sensor-board: Create basic PCB layout
    [sensor-board.kicad_pcb, sensor-board.kicad_sch]
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2026-07-21 sensor-board: Finalize the first iteration
    [sensor-board.kicad_pcb, sensor-board.kicad_sch]
2026-07-21 ci: Don't promote DRC warnings to errors (temporary)
    The KiBot DRC preflight promoted every warning to an error, but the
    first-iteration board still produces many benign DRC warnings across
    several categories:
    - silk_overlap: overlapping silkscreen reference designators
    - footprint_filters_mismatch: custom footprint library names don't
    match KiCad's default symbol footprint filters
    - missing_footprint: simulation-only parts (voltage sources, net ties)
    legitimately have no PCB footprint
    Set warnings_as_errors: false for DRC, mirroring the ERC preflight, so
    CI still fails on real DRC *errors* (clearance, shorts, unconnected)
    while these cosmetic/library warnings pass. Marked with a TODO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
2026-07-23 repo: Rename project from njordr to vetroplach
    - vetroplach is a more playful name for the anemometer, suggested by
    the author's wife, replacing the Norse god name
    - the board and firmware directories, the shared KiCad symbol and
    footprint libraries, the CI workflows, and every in-file reference
    change in one step so the tree never mixes the two names
    [controller.kicad_sch, interface.kicad_sch, power-supply.kicad_sch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]
2026-07-23 repo: Restructure into pcb/ and firmware/ trees
    - boards and the shared component library move under pcb/ and the
    firmware crate under firmware/vetroplach, so the hardware and
    firmware trees are cleanly separated
    - the crate is renamed from vetroplach-firmware to vetroplach; the
    firmware/ prefix already says what it is
    - pcb/components keeps sitting next to the boards, so the relative
    KIPRJMOD library-table references keep resolving unchanged
    - the workflow path filters and working directories follow the moved
    trees, so the per-tree CI keeps triggering until the flake pipeline
    replaces it
    - the dead vetroplach.binaryName editor key is dropped instead of
    carried over; launch.jso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
    [BM04B-SRSS-TBT.stp, C-0603.step, C-0805.step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]
2026-07-23 pcb: Make the library paths relative
    - the symbol table and the Sim.Library properties pinned absolute
    paths into one specific checkout, so any clone, worktree, or CI
    sandbox failed to resolve the libraries; the sim paths also missed
    the spice/ subdirectory, so the opamp model never resolved at all
    - KIPRJMOD matches how the footprint table and the sensor board
    already reference the shared library
    [signal-priming.kicad_sch, vetroplach-board.kicad_pcb]
2026-07-23 flake: Add the unified nix build environment
    - the per-crate flake installed the Xtensa toolchain impurely at shell
    entry via espup and patched binaries on every machine; pinning the
    esp-rs and crosstool-NG release tarballs by hash makes the toolchain
    a pure derivation that works inside the flake-check sandbox
    - the crosstool-NG GCC is required even without C dependencies because
    the esp-rs rustc target spec names it as the linker driver
    - crane builds the firmware checks: fmt, clippy over bins and
    examples, and the release build; build-std sysroot crates are
    vendored next to the crate lock so checks resolve offline
    - headless kicad-cli DRC/ERC gates cover both boards, staging ea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
2026-07-23 ci: Run the pipeline through the flake
    - the kibot container action and the xtensa-toolchain action each
    pinned their own toolchains, which could drift from local builds;
    running nix build .#ci-format/.#ci-clippy/.#ci-check makes CI and a
    developer run the identical commands against the same pins
    - the third-party setup actions are pinned to major release tags,
    which limits drift to upstream point releases within each major
    - fabrication outputs come from the flake kibot package per board and
    upload as artifacts
2026-07-23 claude: Adopt the agentic environment
    - CLAUDE.md carries the build, flash, verification, and git-workflow
    doctrine; the commit and branch skills load their detailed process
    only when invoked
    - gitlint plus the custom rules enforce the commit-message format that
    the skills describe, and CI runs it on every pull request
    - the firmware crate's old CLAUDE.md is replaced by a path-scoped rules
    file that loads only under firmware/vetroplach/; the pin map is
    corrected against the current sources, and the stale documentation,
    testing, and workflow sections are dropped
2026-07-23 docs: Rewrite the README for the workspace layout
    - the README described only the firmware crate; the repository also
    carries two boards, a shared library, and the nix gates, so it now
    documents the layout and the per-tree entry commands
2026-07-23 pcb: Tidy the kibot comments
    - the header and warning-list comments were sentence fragments with
    parenthetical asides, and the variant comment used filler wording
    and spelled placeholder as two words, out of line with the repo
    doctrine of proper-sentence comments
    - the DOCS output names carried trailing whitespace, harmless to the
    YAML parser but untidy
2026-07-23 pcb: Remove duplicate name keys from kibot outputs
    - the JLCPCB, DOCS_schematics, and DOCS_pcb blocks declared name twice,
    once as the output id and once duplicating options.output; YAML keeps
    the last value, so the ids silently resolved to the filename patterns
    and the outputs could not be selected by name
2026-07-23 repo: Prune unneeded gitignore patterns
    - the KiCad template section listed the autosave-lock pattern twice
    with inconsistent escaping and carried three entries subsumed by
    *-bak*; each pattern now appears once with minimal escaping
    - the Cargo section carried a debug/ entry subsumed by target/
    - the espup-era .rustup/ entry outlived the switch to the pinned nix
    toolchain; nothing creates a repo-local .rustup/ anymore
    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
2026-07-23 firmware: Unify the probe-rs chip identifier
    - the debug launch config spelled the chip ESP32-S3 while every other
    reference in the repo uses the probe-rs target-database name esp32s3;
    one spelling keeps the configs consistent and greppable
2026-07-23 firmware: Fix the stale PWM frequency comment
    - the comment above the timer configuration said 20 kHz while the code
    configures the 40 kHz carrier that the firmware rules document
    [main.rs]
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2026-07-23 pcb: Exclude the starved thermal violations
    - KiCad 10 refills the vetroplach-board GND pour with a single thermal
    spoke on nine pads that the saved KiCad 9 fill connected with two,
    so the kibot preflight, which refills zones before its DRC, failed
    the fab pipeline while the flake gate checked the saved fill
    - the pads stay connected through one spoke; the shortfall is accepted
    for the first-iteration board as reviewed exclusions in the project
    file, next to the one that already existed
2026-07-23 flake: Refill zones in the DRC gate
    - the kibot preflight refills zones before its DRC through
    check_zone_fills, while the flake gate validated the fills saved in
    the board file, so the local check stayed green while the fab
    pipeline failed on the starved thermals
    - kicad-cli pcb drc --refill-zones recomputes the fills the same way,
    so both gates now judge the same copper

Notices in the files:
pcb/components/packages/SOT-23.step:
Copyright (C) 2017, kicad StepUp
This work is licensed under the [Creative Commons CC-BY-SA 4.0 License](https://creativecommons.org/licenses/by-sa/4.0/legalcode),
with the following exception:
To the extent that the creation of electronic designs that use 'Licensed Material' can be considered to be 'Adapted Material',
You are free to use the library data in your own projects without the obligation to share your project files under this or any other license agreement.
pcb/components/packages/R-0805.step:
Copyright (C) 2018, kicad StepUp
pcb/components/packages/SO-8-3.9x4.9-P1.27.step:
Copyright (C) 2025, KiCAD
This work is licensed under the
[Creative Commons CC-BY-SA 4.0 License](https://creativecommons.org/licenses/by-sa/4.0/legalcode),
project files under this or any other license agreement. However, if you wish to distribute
